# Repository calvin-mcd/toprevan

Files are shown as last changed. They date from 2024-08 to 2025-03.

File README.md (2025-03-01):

# toprevan

The toprevan is a EC (topre) pcb for trashman's [minivan](https://trashman.wiki/keyboards/minivan) keyboad. The pcb supports the [minisub](https://trashman.wiki/community/pcbs/minisub) layout with both the 625U spacebar and the split 275U, 225U spacebars. The pcb has some of the traymout holes of the original minivan pcb but topre housings (and potentially some domes) need cutting to make that work.

Each layout requires its own respective plate. Various plate files can be found in the production folder. But since there are many different plate styles for the various cases out there, beware that plates could not have been tested beforehand.

***VERSIONS***:
In the production folder you will find both the prototype production files and the revision files (as well as various plate files). Please be aware when ordering pcbs of their differences and what aspects have not been confirmed to work yet.
- The prototype is sporting a standard usb port which limits case compatibility a bit but using o-rings like on the travaulta should mitigate that in a bunch of cases. The rgb breakout has not been tested. Otherwise the pcb is fully working.
- The revision is using another USB port for more compatibility. It also sports all of the traymount holes. The rgb breakout has still not been tested. The revision has not been prototyped yet.

## Layout

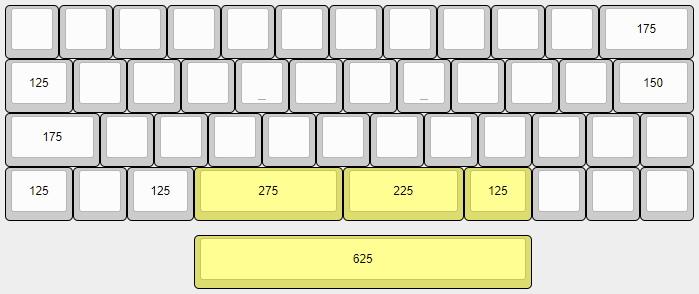
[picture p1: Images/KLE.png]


[Link](https://www.keyboard-layout-editor.com/#/gists/1fa1f216f42ccb54e6a5849ecc492d73)

## Firmware

The basic EC firmware is ready to go and the source code is provided for tweaking any settings.

## Plates & Hardware

Plate files are available for OEM (original and deskey housings), for each respective bottom row choice, and for the original plate, Hull and Embrace cases.

Furthermore, you will need 22x 10mm M2 screws and M2 nuts to assemble the pcb. O-rings might help aligning the pcb and usb port in some cases, but is not required.

## Disclaimer

Please note that this project is a work in progress with no guarantees of a working outcome. No-one involved in this project is responsible for any usage issues that may arise. Order at your own risk. Support will not be provided but pull requests will be reviewed and possibly accepted.

## License

Shield: 

This work is licensed under a  
[Creative Commons Attribution-NonCommercial-ShareAlike 4.0 International License](http://creativecommons.org/licenses/by-nc-sa/4.0/).



## Credits

big thanks to petejohanson for feedback and help!

Furthermore, many thanks for feedback, help, references go to Sporkus, Cipulot\#8455 & matthewdias\#2671.

Any questions, contact Calvin0563 on Discord.

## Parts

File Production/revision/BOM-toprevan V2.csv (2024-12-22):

Comment | Designator | Footprint | LCSC | Quantity
1k | R18 | R_0402_1005Metric | C11702 | 1
STM32F401CBUx | U1 | QFN-48-1EP_7x7mm_P0.5mm_EP5.6x5.6mm | C118825 | 1
OPA350 | U5 | SOIC-8_3.9x4.9mm_P1.27mm | C13388 | 1
220p | C15 | C_0402_1005Metric | C1530 | 1
JST SH | J1 | JST_SH_SM04B-SRSS-TB_1x04-1MP_P1.00mm_Horizontal | C160404 | 1
4.7u | C1 | C_0402_1005Metric | C23733 | 1
100 | R3,R4,R5,R6 | R_0402_1005Metric | C25076 | 4
100k | R12,R13,R14,R15,R16,R17,R19,R2,R20,R21,R22,R23,R24,R25 | R_0402_1005Metric | C25741 | 14
10k | R10,R11,R9 | R_0402_1005Metric | C25744 | 3
5k1 | R7,R8 | R_0402_1005Metric | C25905 | 2
PRTR5V0U2X | D1 | SOT-143 | C2827688 | 1
USB_C sink board 1.3mm | J5 | USB4510031A | C3019717 | 1
100n | C10,C14,C16,C17,C6,C7,C8,C9 | C_0402_1005Metric | C307331 | 8
1u | C11,C12,C13 | C_0402_1005Metric | C52923 | 3
XC6206PxxxMR | U3 | SOT-23 | C5446 | 1
74HC4051 | U4,U6 | TSSOP16 | C5645 | 2
500mA | F_USBC1 | Fuse_1206_3216Metric | C70076 | 1
8 MHz | Y1 | Resonator_SMD_Murata_CSTxExxV-3Pin_3.0x1.1mm | C907975 | 1

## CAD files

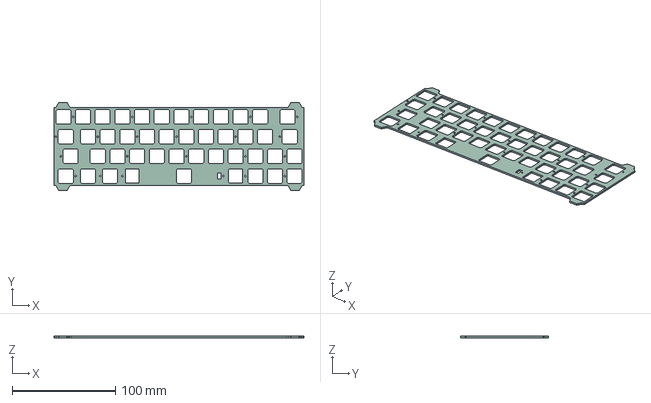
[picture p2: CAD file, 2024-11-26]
Project/Plates/campsite full.step
241.8 x 85.2 x 1.59 mm

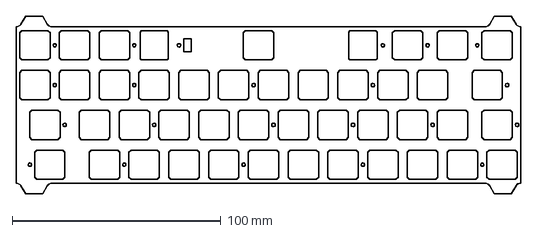
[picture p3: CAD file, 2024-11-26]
Production/plates/campsite/campsite threaded full.dxf
241.8 x 85.2 mm

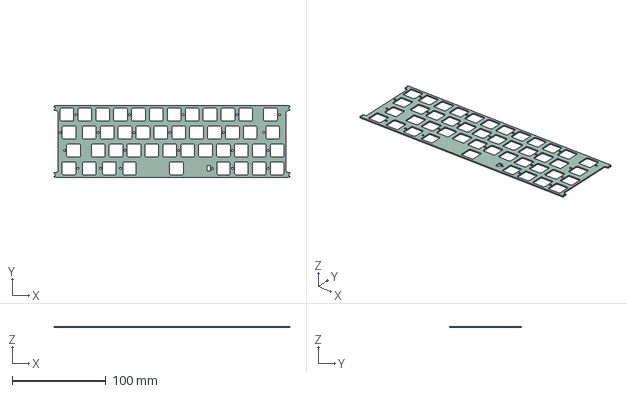
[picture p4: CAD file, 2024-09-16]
Project/Plates/hull full.step
251.2 x 76.2 x 1.20 mm

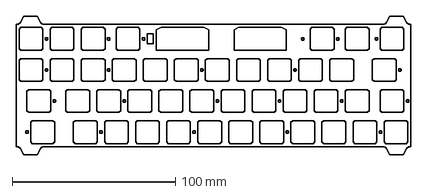
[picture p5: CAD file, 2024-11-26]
Production/plates/campsite/campsite threaded split.dxf
241.8 x 85.2 mm

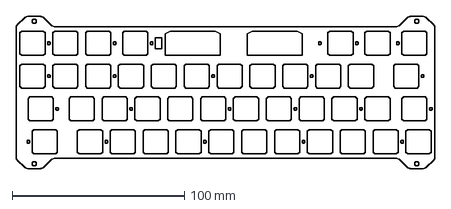
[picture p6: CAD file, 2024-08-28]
Production/plates/hubris/toprevan split.dxf
242.9 x 88.2 mm

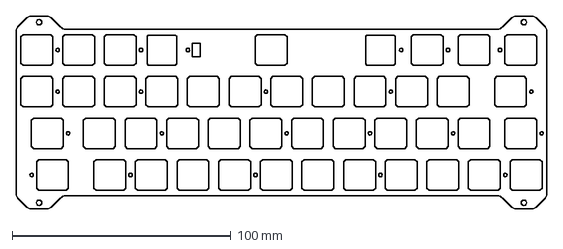
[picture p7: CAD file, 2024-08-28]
Production/plates/hubris/toprevan 625.dxf
242.9 x 88.2 mm

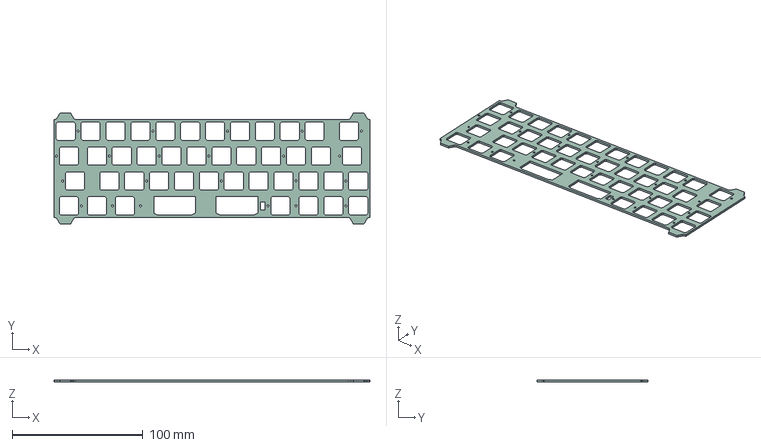
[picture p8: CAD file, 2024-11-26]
Project/Plates/campsite split.step
241.8 x 85.2 x 1.59 mm

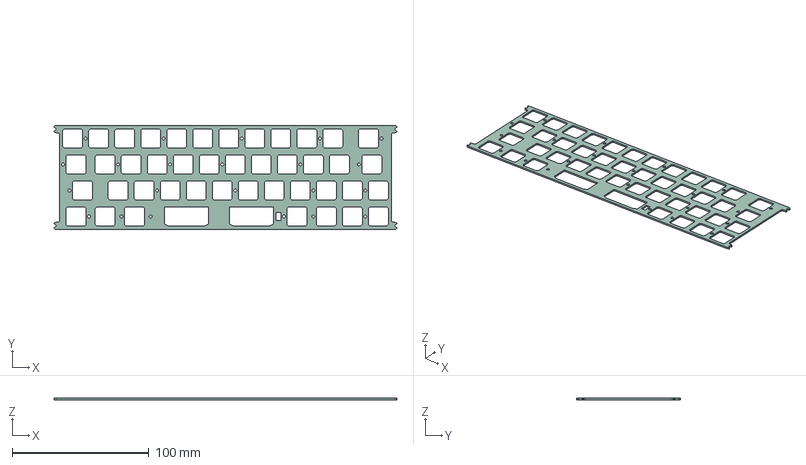
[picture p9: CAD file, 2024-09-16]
Project/Plates/hull split.step
251.2 x 76.2 x 1.20 mm

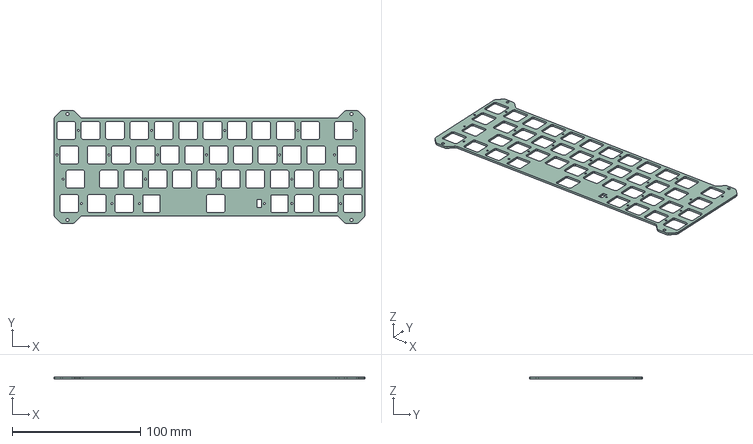
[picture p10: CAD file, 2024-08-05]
Project/Plates/plate 625.step
242.9 x 88.2 x 1.59 mm

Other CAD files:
Project/Plates/camp full.step

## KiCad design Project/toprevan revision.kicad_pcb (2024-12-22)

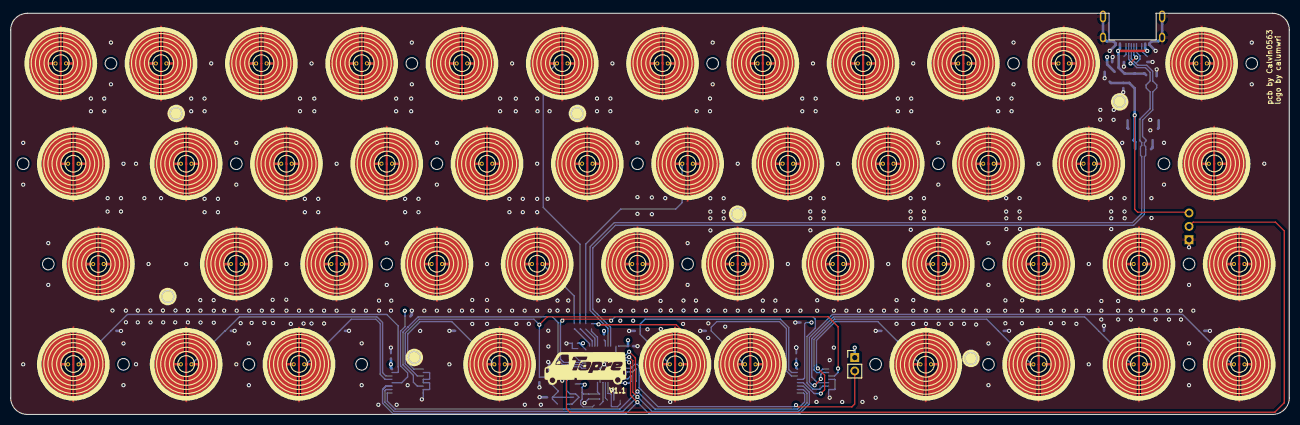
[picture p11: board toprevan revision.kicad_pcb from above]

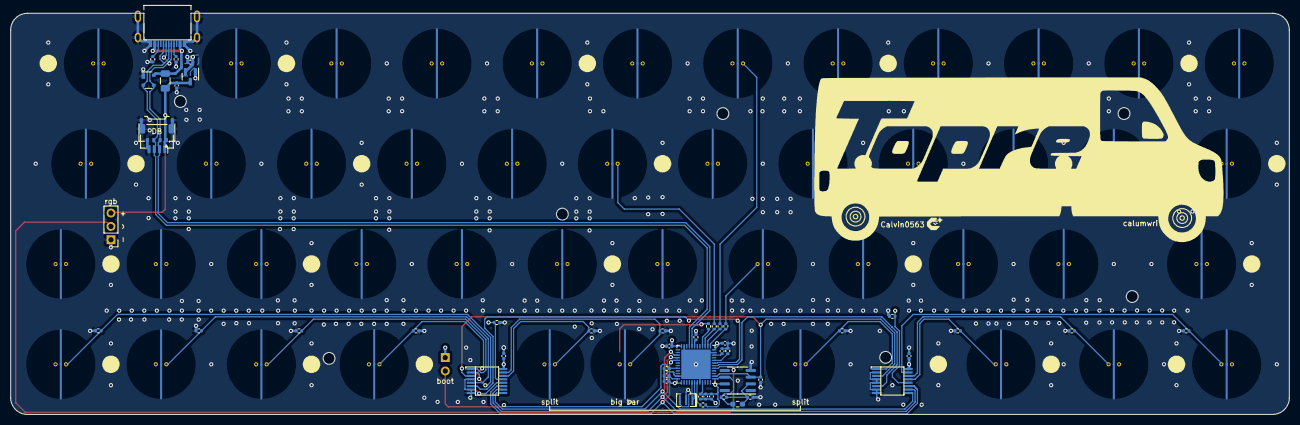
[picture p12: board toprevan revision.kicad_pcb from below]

Board: 4 copper layers, 242.9 x 76.2 mm, 119 parts (50 on the bottom side), 44 nets.

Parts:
C1: 4.7u; C_0402_1005Metric
C6, C7, C8, C9, C10, C14, C16, C17: 100n; C_0402_1005Metric
C11, C12, C13: 1u; C_0402_1005Metric
C15: 220p; C_0402_1005Metric
D1: PRTR5V0U2X; SOT-143
F_USBC1: 500mA; Fuse_1206_3216Metric
H1, H2, H3, H4, H5, H6, H7, H8, H9, H10, H11, H12, H13, H14, H15, H16, H17, H18, H19, H20, H21, H22: MountingHole; HOLE_M2
J1: JST SH; JST_SH_SM04B-SRSS-TB_1x04-1MP_P1.00mm_Horizontal
J2: Pico EZmate; Molex_Pico-EZmate_78171-0004_1x04-1MP_P1.20mm_Vertical
J4: ARGB; PinHeader_1x03_P2.54mm_Vertical
J5: USB_C sink board 1.3mm; USB4510031A
JP1: Ext_Res; R_0603_1608Metric_Pad0.98x0.95mm_HandSolder
R2, R12, R13, R14, R15, R16, R17, R19, R20, R21, R22, R23, R24, R25: 100k; R_0402_1005Metric
R3, R4, R5, R6: 100; R_0402_1005Metric
R7, R8: 5k1; R_0402_1005Metric
R9, R10, R11: 10k; R_0402_1005Metric
R18: 1k; R_0402_1005Metric
SW1: BOOT0; PinHeader_1x02_P2.54mm_Vertical
SW_EC1, SW_EC2, SW_EC3, SW_EC4, SW_EC5, SW_EC6, SW_EC7, SW_EC8, SW_EC9, SW_EC10, SW_EC11, SW_EC12, SW_EC13, SW_EC14, SW_EC15, SW_EC16, SW_EC17, SW_EC18, SW_EC19, SW_EC20, SW_EC21, SW_EC22, SW_EC23, SW_EC24, SW_EC25, SW_EC26, SW_EC27, SW_EC28, SW_EC29, SW_EC30, SW_EC31, SW_EC32, SW_EC33, SW_EC34, SW_EC35, SW_EC36, SW_EC37, SW_EC38, SW_EC39, SW_EC40, SW_EC41, SW_EC42, SW_EC43, SW_EC44, SW_EC45, SW_EC46: Topre; ecs_pad_1U_no_ring
U1: STM32F401CBUx; QFN-48-1EP_7x7mm_P0.5mm_EP5.6x5.6mm
U3: XC6206PxxxMR; SOT-23
U4, U6: 74HC4051; TSSOP16
U5: OPA350; SOIC-8_3.9x4.9mm_P1.27mm
Y1: 8 MHz; Resonator_SMD_Murata_CSTxExxV-3Pin_3.0x1.1mm

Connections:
+5V: C12.1, F_USBC1.2, J1.1, J2.1, J4.3, U3.3 (VI)
/CC1: J5.A5 (CC1), R7.1
/CC2: J5.B5 (CC2), R8.1
ADC: JP1.1 (A), R12.2, U1.13 (PA3), U5.6 (OUT)
AMUX_SEL_0: U1.41 (PB5), U4.11 (S0), U6.11 (S0)
AMUX_SEL_1: U1.40 (PB4), U4.10 (S1), U6.10 (S1)
AMUX_SEL_2: U1.39 (PB3), U4.9 (S2), U6.9 (S2)
APLEX_EN_PIN_0: U1.18 (PB0), U4.6 (~E)
APLEX_EN_PIN_1: U1.19 (PB1), U6.6 (~E)
APLEX_OUT_PIN_0: C15.2, U1.14 (PA4), U4.3 (A), U5.3 (IN+), U6.3 (A)
ARGB_3V3: J4.2, U1.17 (PA7)
BOOT0: R11.1, SW1.2 (B), U1.44 (BOOT0)
BOOT1: R10.2, U1.20 (PB2)
COL0: R15.1, SW_EC1.2, SW_EC13.2, SW_EC25.2, SW_EC37.2, U4.15 (A2)
COL1: R14.1, SW_EC2.2, SW_EC14.2, SW_EC26.2, SW_EC38.2, U4.14 (A1)
COL2: R13.1, SW_EC3.2, SW_EC15.2, SW_EC27.2, SW_EC39.2, U4.13 (A0)
COL3: R16.1, SW_EC4.2, SW_EC16.2, SW_EC28.2, U4.12 (A3)
COL4: R17.1, SW_EC5.2, SW_EC17.2, SW_EC29.2, SW_EC40.2, U4.1 (A4)
COL5: R21.1, SW_EC6.2, SW_EC18.2, SW_EC30.2, SW_EC41.2, U6.15 (A2)
COL6: R20.1, SW_EC7.2, SW_EC19.2, SW_EC31.2, SW_EC42.2, U6.14 (A1)
COL7: R19.1, SW_EC8.2, SW_EC20.2, SW_EC32.2, U6.13 (A0)
COL8: R22.1, SW_EC9.2, SW_EC21.2, SW_EC33.2, SW_EC43.2, U6.12 (A3)
COL9: R23.1, SW_EC10.2, SW_EC22.2, SW_EC34.2, SW_EC44.2, U6.1 (A4)
COL10: R24.1, SW_EC11.2, SW_EC23.2, SW_EC35.2, SW_EC45.2, U6.5 (A5)
COL11: R25.1, SW_EC12.2, SW_EC24.2, SW_EC36.2, SW_EC46.2, U6.2 (A6)
D+: D1.2 (I/O1), J1.3, J2.3, J5.A6 (D+), J5.B6 (D+), U1.33 (PA12)
D-: D1.3 (I/O2), J1.2, J2.2, J5.A7 (D-), J5.B7 (D-), U1.32 (PA11)
GND: C1.2, C6.2, C7.2, C8.2, C9.2, C10.2, C11.2, C12.2, C13.2, C14.2, C15.1, C16.2, C17.2, D1.1 (GND), J1.4, J1.MP (MountPin), J2.4, J2.MP (MountPin), J4.1, J5.A1 (GND), J5.A12 (GND), J5.S1 (SHIELD), R7.2, R8.2, R10.1, R11.2, R13.2, R14.2, R15.2, R16.2, R17.2, R18.2, R19.2, R20.2, R21.2, R22.2, R23.2, R24.2, R25.2, SW_EC1.3, SW_EC2.3, SW_EC3.3, SW_EC4.3, SW_EC5.3, SW_EC6.3, SW_EC7.3, SW_EC8.3, SW_EC9.3, SW_EC10.3, SW_EC11.3, SW_EC12.3, SW_EC13.3, SW_EC14.3, SW_EC15.3, SW_EC16.3, SW_EC17.3, SW_EC18.3, SW_EC19.3, SW_EC20.3, SW_EC21.3, SW_EC22.3, SW_EC23.3, SW_EC24.3, SW_EC25.3, SW_EC26.3, SW_EC27.3, SW_EC28.3, SW_EC29.3, SW_EC30.3, SW_EC31.3, SW_EC32.3, SW_EC33.3, SW_EC34.3, SW_EC35.3, SW_EC36.3, SW_EC37.3, SW_EC38.3, SW_EC39.3, SW_EC40.3, SW_EC41.3, SW_EC42.3, SW_EC43.3, SW_EC44.3, SW_EC45.3, SW_EC46.3, U1.8 (VSSA), U1.23 (VSS), U1.35 (VSS), U1.47 (VSS), U1.49 (VSS), U3.1 (GND), U4.2 (A6), U4.4 (A7), U4.5 (A5), U4.7 (VEE), U4.8 (GND), U5.4 (V-), U6.4 (A7), U6.7 (VEE), U6.8 (GND), Y1.2
NRST: R9.2, U1.7 (NRST)
unnamed: JP1.2 (B), R12.1, R18.1, U5.2 (IN-)
unnamed: R2.1, U1.31 (PA10)
unnamed: R6.2, U1.25 (PB12)
unnamed: R4.2, U1.26 (PB13)
unnamed: R5.2, U1.27 (PB14)
unnamed: R3.2, U1.28 (PB15)
unnamed: C1.1, U1.22 (VCAP1)
ROW0: R4.1, SW_EC1.1, SW_EC2.1, SW_EC3.1, SW_EC4.1, SW_EC5.1, SW_EC6.1, SW_EC7.1, SW_EC8.1, SW_EC9.1, SW_EC10.1, SW_EC11.1, SW_EC12.1
ROW1: R5.1, SW_EC13.1, SW_EC14.1, SW_EC15.1, SW_EC16.1, SW_EC17.1, SW_EC18.1, SW_EC19.1, SW_EC20.1, SW_EC21.1, SW_EC22.1, SW_EC23.1, SW_EC24.1
ROW2: R6.1, SW_EC25.1, SW_EC26.1, SW_EC27.1, SW_EC28.1, SW_EC29.1, SW_EC30.1, SW_EC31.1, SW_EC32.1, SW_EC33.1, SW_EC34.1, SW_EC35.1, SW_EC36.1
ROW3: R3.1, SW_EC37.1, SW_EC38.1, SW_EC39.1, SW_EC40.1, SW_EC41.1, SW_EC42.1, SW_EC43.1, SW_EC44.1, SW_EC45.1, SW_EC46.1
VBAT: C6.1, C7.1, C8.1, C9.1, C10.1, C11.1, C13.1, C14.1, C16.1, C17.1, R2.2, R9.1, SW1.1 (A), U1.1 (VBAT), U1.9 (VREF+), U1.24 (VDD), U1.36 (VDD), U1.48 (VDD), U3.2 (VO), U4.16 (VCC), U5.7 (V+), U6.16 (VCC)
VCC: D1.4 (VCC), F_USBC1.1, J5.A4 (VBUS), J5.A9 (VBUS)
XTAL0: U1.5 (PH0), Y1.3
XTAL1: U1.6 (PH1), Y1.1

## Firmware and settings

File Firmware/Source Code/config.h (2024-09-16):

/* Copyright 2023 sporkus
 *
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
 * You should have received a copy of the GNU General Public License
 * along with this program.  If not, see <http://www.gnu.org/licenses/>.
 */

#pragma once

// --- EC matrix user configuration ---
// Actuation/release threshold = idle + offset
// Larger offset = More key travel distance, less sensitive
// Sensitivity can be adjusted using keycode: EC_AP_I/EC_AP_D
#define ACTUATION_OFFSET 150
#define RELEASE_OFFSET 170
#define DEFAULT_IDLE 500      // default value before tuning is completed
#define ECSM_DEBUG         // enables printing ec config and ADC readings
#define EC_MATRIX            // allows ec code to be enabled with ifdef

// enables tuning ec config every power cycle, disable to reduce write cycle to flash
//#define ECSM_TUNE_ON_BOOT

/* key matrix size */
#define MATRIX_ROWS 4
#define MATRIX_COLS 12

/* Custom matrix pins and port select array */
#define MATRIX_ROW_PINS \
    { B13, B14, B12, B15 }
#define MATRIX_COL_CHANNELS \
    { \
       2, 1, 0, 3, 4, \
       10, 9, 8, 11, 12, 13, 14 \
    }

/* Hardware peripherals pins */
#define MUX_SEL_PINS \
    { B5, B4, B3 }

#define MUX_EN_PINS \
    { B0, B1 }

#define DISCHARGE_PIN A4
#define ANALOG_PORT A3

/* COL2ROW, ROW2COL */
#define DIODE_DIRECTION COL2ROW

/* Debounce reduces chatter (unintended double-presses) - set 0 if debouncing is not needed */
//#define DEBOUNCE 5

/* Mechanical locking support. Use KC_LCAP, KC_LNUM or KC_LSCR instead in keymap */
#define LOCKING_SUPPORT_ENABLE

/* Locking resynchronize hack */
#define LOCKING_RESYNC_ENABLE

// --- Persistent Storage config ---
// Data size is in bytes. uint16_t = 2 bytes
// data block size needs to be uint16_t array length * 2
// Two addition words for actuation offsets and one byte for configuration check
#define EECONFIG_KB_DATA_SIZE ((MATRIX_ROWS * MATRIX_COLS + 2) * 2 + 1)

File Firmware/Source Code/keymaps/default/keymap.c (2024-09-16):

/* SPDX-License-Identifier: GPL-2.0-or-later */

#include QMK_KEYBOARD_H

const uint16_t PROGMEM keymaps[][MATRIX_ROWS][MATRIX_COLS] = {

[0] = LAYOUT( \
  KC_TRNS, KC_TRNS, KC_TRNS, KC_TRNS, KC_TRNS, KC_TRNS, KC_TRNS, KC_TRNS, KC_TRNS, KC_TRNS, KC_TRNS, KC_TRNS, \
  KC_TRNS, KC_TRNS, KC_TRNS, KC_TRNS, KC_TRNS, KC_TRNS, KC_TRNS, KC_TRNS, KC_TRNS, KC_TRNS, KC_TRNS, KC_TRNS, \
  KC_TRNS, KC_TRNS, KC_TRNS, KC_TRNS, KC_TRNS, KC_TRNS, KC_TRNS, KC_TRNS, KC_TRNS, KC_TRNS, KC_TRNS, KC_TRNS, \
  KC_TRNS, KC_TRNS, KC_TRNS, KC_TRNS,      KC_TRNS,          KC_TRNS,              KC_TRNS, KC_TRNS, KC_TRNS
),
[1] = LAYOUT( \
  KC_TRNS, KC_TRNS, KC_TRNS, KC_TRNS, KC_TRNS, KC_TRNS, KC_TRNS, KC_TRNS, KC_TRNS, KC_TRNS, KC_TRNS, KC_TRNS, \
  KC_TRNS, KC_TRNS, KC_TRNS, KC_TRNS, KC_TRNS, KC_TRNS, KC_TRNS, KC_TRNS, KC_TRNS, KC_TRNS, KC_TRNS, KC_TRNS, \
  KC_TRNS, KC_TRNS, KC_TRNS, KC_TRNS, KC_TRNS, KC_TRNS, KC_TRNS, KC_TRNS, KC_TRNS, KC_TRNS, KC_TRNS, KC_TRNS, \
  KC_TRNS, KC_TRNS, KC_TRNS, KC_TRNS,      KC_TRNS,          KC_TRNS,              KC_TRNS, KC_TRNS, KC_TRNS
),
[2] = LAYOUT( \
  KC_TRNS, KC_TRNS, KC_TRNS, KC_TRNS, KC_TRNS, KC_TRNS, KC_TRNS, KC_TRNS, KC_TRNS, KC_TRNS, KC_TRNS, KC_TRNS, \
  KC_TRNS, KC_TRNS, KC_TRNS, KC_TRNS, KC_TRNS, KC_TRNS, KC_TRNS, KC_TRNS, KC_TRNS, KC_TRNS, KC_TRNS, KC_TRNS, \
  KC_TRNS, KC_TRNS, KC_TRNS, KC_TRNS, KC_TRNS, KC_TRNS, KC_TRNS, KC_TRNS, KC_TRNS, KC_TRNS, KC_TRNS, KC_TRNS, \
  KC_TRNS, KC_TRNS, KC_TRNS, KC_TRNS,      KC_TRNS,          KC_TRNS,              KC_TRNS, KC_TRNS, KC_TRNS
),
[3] = LAYOUT( \
  KC_TRNS, KC_TRNS, KC_TRNS, KC_TRNS, KC_TRNS, KC_TRNS, KC_TRNS, KC_TRNS, KC_TRNS, KC_TRNS, KC_TRNS, KC_TRNS, \
  KC_TRNS, KC_TRNS, KC_TRNS, KC_TRNS, KC_TRNS, KC_TRNS, KC_TRNS, KC_TRNS, KC_TRNS, KC_TRNS, KC_TRNS, KC_TRNS, \
  KC_TRNS, KC_TRNS, KC_TRNS, KC_TRNS, KC_TRNS, KC_TRNS, KC_TRNS, KC_TRNS, KC_TRNS, KC_TRNS, KC_TRNS, KC_TRNS, \
  KC_TRNS, KC_TRNS, KC_TRNS, KC_TRNS,      KC_TRNS,          KC_TRNS,              KC_TRNS, KC_TRNS, KC_TRNS
)

};

/* Encoder */
#ifdef ENCODER_MAP_ENABLE
const uint16_t PROGMEM encoder_map[][NUM_ENCODERS][NUM_DIRECTIONS] = {
    [0] =   { ENCODER_CCW_CW(KC_VOLD, KC_VOLU) },
    [1] =   { ENCODER_CCW_CW(_______, _______) },
    [2] =   { ENCODER_CCW_CW(_______, _______) },
    [3] =   { ENCODER_CCW_CW(_______, _______) }
};
#endif

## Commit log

2024-06-07 production files, plate files
    [plate split-Edge_Cuts.dxf, plate split.kicad_pcb, plate-Edge_Cuts.dxf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]
2024-08-05 pcb & plate revision
    move mux, add cutout for all plates for boot
    [analog.kicad_sch, matrix.kicad_sch, mounting.kicad_sch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]
2024-08-28 proto ready
    [BOM-toprevan.csv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]
2024-09-16 firmware wip
    [hull full.step, hull split.step, matrix.kicad_sch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]
2024-11-26 plate generation
    [2u measurements.kicad_pcb, 2u measurements.step, camp full.step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]
2024-12-22 publishing changes
    [2u measurements.kicad_pcb, 2u measurements.step, BOM-toprevan V2.csv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]
2025-03-01 Create toprevan prototype-2025-03-01_170748.zip

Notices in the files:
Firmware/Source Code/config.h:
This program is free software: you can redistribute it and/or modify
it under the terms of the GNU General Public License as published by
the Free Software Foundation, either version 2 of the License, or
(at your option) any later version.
